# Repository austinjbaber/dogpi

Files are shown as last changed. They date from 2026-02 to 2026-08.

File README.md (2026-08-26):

# DogPi

**A self-contained Raspberry Pi appliance for logging dog bathroom activity, checking recent history, and viewing local weather from a tactile three-button interface.**

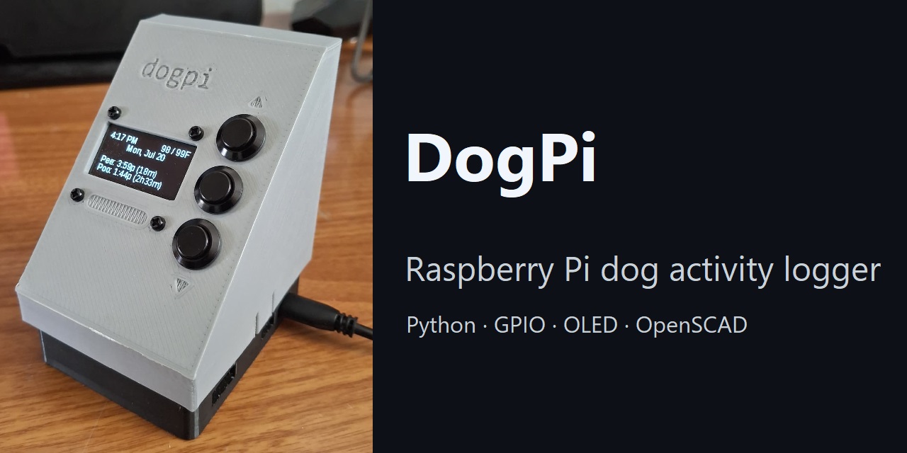
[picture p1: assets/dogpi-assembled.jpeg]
Assembled DogPi device


## Project overview

Coordinating pet care in a shared household can be surprisingly difficult. DogPi provides a simple, shared record of bathroom breaks on a purpose-built device that stays near the door. With a few button presses, anyone can log a pee, poop, or both, including an estimated time for an event recorded later. The OLED shows how long it has been and the current weather at a glance.

The project combines software, electronics, and mechanical design into one working product. It uses a state-driven embedded UI, GPIO input, durable local storage, a fault-tolerant weather integration, automated tests, and a custom 3D-printable enclosure.

## Key features

- Physical three-button interface with a six-state OLED UI
- Timestamped activity logging for pee, poop, or both, with an adjustable "how long ago" picker
- At-a-glance status showing the most recent events and current temperature
- Current weather stats and a scrollable hourly forecast from Open-Meteo
- Cached weather data with refresh throttling and stale-data fallback
- 5 configurable animated idle screens with real-time motion and bounded frame pacing
- Undo support and atomic JSON persistence across restarts
- Parametric OpenSCAD enclosure with ready-to-print STL files
- Automated regression tests for networking, caching, parsing, screen conversion, and timezones

## Architecture and engineering highlights

DogPi keeps hardware concerns, application state, screen rendering, and external services separated. `app.py` acts as the composition root: it loads configuration, creates the HTTP and weather services, injects the weather dependency into the UI, and then registers GPIO callbacks.

```text
Three GPIO buttons ──> input callbacks ──> UI state + screen rendering ──> SH1106 OLED
                                              │
                                              └──> atomic JSON event log

config.json ──> app.py
                  ├──> HttpService ──> WeatherService ──> Open-Meteo
                  │                     ├── implements IWeatherService
                  │                     └── injected clock
                  │
                  └──> screens.py <──── IWeatherService
```

Notable design decisions include:

- **Testable service boundaries:** screens depend on `IWeatherService`, while `WeatherService` depends on `IHttpService`. Tests can supply fakes without GPIO hardware or live network calls.
- **Resilient weather behavior:** refresh attempts are throttled, failed requests preserve the last successful result, and the UI identifies cached results as stale rather than discarding useful data.
- **Deterministic time handling:** the weather service accepts an injectable clock and interprets forecast values in the timezone returned by the API.
- **Safe local persistence:** events are first written to a temporary file and committed with `os.replace`, reducing the risk of a partially written log.
- **Hardware-aware animation:** idle renderers update motion using elapsed time rather than frame count. Rendering cadence is capped separately at 40 FPS to balance smoothness against CPU and I2C load.
- **Configuration outside the code:** coordinates, units, requested forecast fields, refresh timing, and forecast intervals live in `config.json`.

## Hardware and enclosure

| Component | Details |
|---|---|
| Computer | Raspberry Pi with GPIO and I2C. Enclosure designed for a Pi Zero 2 W |
| Display | 1.3-inch SH1106 OLED, 128 × 64, I2C (`0x3C`) |
| Controls | 3x momentary buttons: UP on GPIO 22, SELECT on GPIO 27, DOWN on GPIO 17 |
| Enclosure | Two-part parametric OpenSCAD design with committed base and lid STLs |

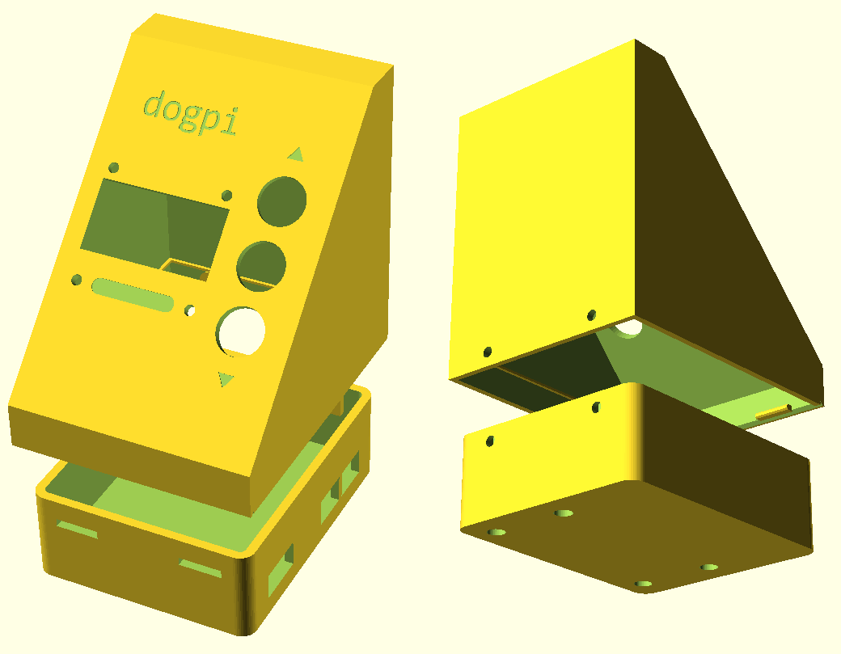
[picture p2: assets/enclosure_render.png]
Rendered DogPi enclosure


The enclosure integrates the Pi, display, and three vertically arranged 12 mm panel-mount buttons into an angled desktop control panel. Its OpenSCAD source exposes the following variables so tolerances can be adapted to a specific printer or filament:
- Fit
- Wall thickness
- Panel angle
- Port clearance
- Button spacing
- Front-tab and captive-nut closure clearances

See [`cad/README.md`](cad/README.md) for dimensions, printing instructions, and fit details.

## UI and controls

The interface is organized around six explicit modes:

- **Idle:** 5 dynamic, burn in-resistant animated backgrounds and DVD-style bouncing clock
- **Status:** Current date and time, most recent pee and poop times, and current local temp/feels-like temp
- **Menu:** Select from log pee/poo/both, undo, current weather, and forecast
- **When:** Selectable hours and 0/15/30/45-minute offset to log an event
- **Weather:** Scrollable current weather conditions
- **Forecast:** Scrollable hourly forecast (24-hour by default)

| Screen | UP | SELECT | DOWN |
|---|---|---|---|
| **Idle** | Cycle backgrounds | Open status | Cycle font |
| **Status** | — | Open menu | — |
| **Menu** | Previous | Select | Next |
| **When** | Increment | Next field / confirm | Decrement |
| **Weather** | Scroll up | — | Scroll down |
| **Forecast** | Scroll up | — | Scroll down |

Hold **SELECT** for 0.6 seconds to return to previous mode. After 25 seconds without input, the display returns to idle mode.

## Setup and usage

### 1. Enable I2C

```bash
sudo raspi-config
# Interface Options -> I2C -> Enable
sudo reboot
```

OLED can be checked after reboot with `i2cdetect -y 1`
The default display address is `0x3C`.

### 2. Install dependencies

```bash
sudo apt update
sudo apt install -y python3-pip i2c-tools fonts-dejavu fonts-liberation fonts-freefont-ttf
pip3 install -r requirements.txt
```

### 3. Configure weather

Weather uses Open-Meteo and does not require an API key.
Edit `config.json` to set:
- `request_parameters.latitude` and `request_parameters.longitude` for the forecast location
- `request_parameters` for units and requested current/daily/hourly fields
- `refresh_interval_seconds` for the minimum interval between attempts (default: 600)
- `forecast_horizon_hours` for the number of upcoming entries retained (default: 24)

The committed coordinates point to Tucson, Arizona.

### 4. Run DogPi

Run from the project directory so the event log is read and written there:

```bash
python3 app.py
```

Events are stored locally in `dog_log.json`:

```json
{
  "events": [
    {"type": "dog", "value": "pee", "ts": "2026-02-18T14:30:00"},
    {"type": "dog", "value": "both", "ts": "2026-02-18T08:15:00"}
  ]
}
```

## Tests

Run the complete suite from the project directory:

```bash
python3 -m pytest -q
```

The tests exercise time and direction helpers, HTTP transport failures, weather parsing and caching, refresh throttling, stale-data fallback, timezone interpretation, dependency reuse, and conversion of service models into OLED-ready views.

## Project structure

```text
dogpi/
├── app.py                     Root, main display loop
├── config.py                  Configuration
├── config.json                Weather location, fields, units, and timing
├── hardware.py                GPIO buttons, SH1106 setup, shared fonts
├── inputs.py                  Button callbacks, state transitions
├── screens.py                 UI state, view models, and OLED rendering
├── state.py                   Atomic event persistence and lookup helpers
├── helpers/                   Time, direction, and numeric helpers
├── idle/                      Idle renderer, animated backgrounds
├── services/
│   ├── http/                  HTTP interface, implementation, response model
│   └── weather/               Weather interface, adapter, cache, data models
├── cad/                       Parametric OpenSCAD source, printable STLs
├── assets/                    Assembled device photo, enclosure render
├── tests/                     Automated regression suite
└── requirements.txt           Python dependencies
```

### Idle animation tuning

Idle motion uses elapsed seconds (`dt`), with speed constants expressed in per-second units. Frame pacing is configured independently in `idle/__init__.py`:

```python
IDLE_TARGET_FPS = 40.0
```

For an SH1106 display over I2C, 24–40 FPS is a practical tuning range depending on the desired smoothness and available CPU/I2C capacity.

## Potential next steps

- Add a short animated demo and a full video walkthrough of the hardware, UI, and enclosure
- Expand the weather screen with a navigable multi-day forecast
- Reuse the HTTP service abstraction for additional features
- Implement test automation with GitHub Actions

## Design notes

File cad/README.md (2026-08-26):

# DogPi enclosure CAD

This directory contains the printable enclosure for DogPi. The enclosure is
designed around a **Raspberry Pi Zero 2 W**, a **1.3-inch SH1106 OLED**, and
three **12 mm momentary panel-mount buttons** arranged vertically on the angled
control deck. Dimensions in the OpenSCAD source are in millimetres.

## Files

| File | Description |
| --- | --- |
| `dogpi.scad` | Parametric OpenSCAD source for the base, lid, cutouts, and markings. |
| `base.stl` | Ready-to-slice base. Its mesh bounds are 60 × 75 × 25 mm. |
| `lid.stl` | Ready-to-slice lid. Its mesh bounds are approximately 64.2 × 112.0 × 64.5 mm. |

## Intended hardware

### Raspberry Pi

The model uses the Raspberry Pi Zero 2 W board outline and mounting pattern:

| Feature | Modelled value |
| --- | ---: |
| PCB outline | 65 × 30 mm |
| Mounting-hole spacing | 58 × 23 mm |
| Hole inset from PCB edges | 3.5 mm |
| Printed clearance-hole diameter | 2.8 mm |
| Exterior screw-head counterbore | 5 mm diameter × 3 mm deep |

The Pi is rotated 90 degrees inside the base so the mini-HDMI and two micro-USB
connectors face the right wall. The port cutouts are based on connector center
positions from the Pi drawing.

### OLED

The lid is intended for a 1.3-inch, 128 × 64 SH1106 I2C OLED module with this
mounting geometry:

| Feature | Modelled value |
| --- | ---: |
| Visible-window opening | 34 × 18 mm |
| Mounting-hole spacing | 30.4 × 28.5 mm |
| Printed mounting-hole diameter | 2.75 mm |

The window is intentionally smaller than the module PCB. Compare these values
with the drawing or a physical measurement of your module before printing;
boards sold as “1.3-inch SH1106” may not all use the same PCB or hole pattern.

### Buttons

The control deck accepts three nominal 12 mm panel-mount momentary buttons:

| Feature | Modelled value |
| --- | ---: |
| Printed panel-hole diameter | 12.2 mm |
| Vertical centre-to-centre spacing | 16 mm |
| Arrangement | UP / SELECT / DOWN |

Check the diameter of the threaded barrel rather than the button-cap diameter.

### Fasteners

The complete enclosure uses:

- 8 × M2.5 × 8 mm screws
- 2 × M2.5 × 6 mm screws
- 10 × M2.5 nuts
- 4 × M2.5 washers (1 mm thick)

Four screw-and-nut sets mount the Raspberry Pi and four mount the OLED. The
1 mm washers provide the intended spacing for the Pi board. The remaining two
nuts drop into the rear closure pockets. An 8 mm screw can be used for
the closure if that is what the standoff kit provides, but it may extend
into the wiring cavity.

### Lid closure and assembly

There are two rigid front tuck tabs and two rear captive-nut screws.

1. Insert one M2.5 nut into each open slot in the two rear base bosses.
2. Hold the rear of the lid slightly raised and insert both front tabs into the
   receiver slots.
3. Pivot the rear of the lid down. Do not force the lid as a fixed hinge.
   Continue until the three-sided internal stop lip rests on the base rim.
4. Insert an M2.5 screw through each rear lid hole and tighten it into the
   captive nut.

The closure screws use the same M2.5 hardware as the Pi mounts. Their
printed clearance holes are 3.0 mm rather than the Pi holes' 2.8 mm because the
rear screws pass horizontally through two printed walls and need reliable FDM
clearance. The rear holes are not counterbored.

Each default front tab is 11 mm wide, and each receiver is 11.5 mm wide for
0.25 mm clearance at either side. The two independent receivers tolerate minor
front-wall bowing better than one long, continuous mating feature.

## Important OpenSCAD parameters

Commonly adjusted values are near the top of `dogpi.scad`.

| Parameter | Default | Purpose |
| --- | ---: | --- |
| `$fn` | `48` | Curved-feature resolution. |
| `show_base`, `show_lid` | `true`, `true` | Select which parts are rendered or exported. |
| `show_assembled` | `false` | Switch between assembled and exploded preview. |
| `explode_gap` | `16` | Preview separation between the base and lid. |
| `render_target` | `0` | CLI/export selector described below. |
| `fit` | `0.30` | Lid clearance per side; the lid cavity grows by `2 * fit` in X and Y. |
| `button_hole_clear` | `0.20` | Extra diameter added to each nominal 12 mm button hole. |
| `oled_mount_hole_clear` | `0.25` | Extra diameter added to each nominal 2.5 mm OLED hole. |
| `wall` | `2.4` | Base wall thickness. |
| `floor_t` | `3.8` | Base floor thickness. |
| `face_t` | `3.0` | Lid/control-deck shell thickness. |
| `skirt_t`, `skirt_h` | `1.8`, `8` | Lid skirt wall thickness and overlap. |
| `panel_angle` | `45` | Control-deck angle in degrees. |
| `pi_mount_clear_d` | `2.8` | Pi mounting-hole diameter. |
| `side_port_clear` | `0.50` | Clearance added around the side connector openings. |
| `oled_window_x`, `oled_window_y` | `34`, `18` | OLED viewing-window dimensions. |
| `oled_hole_dx`, `oled_hole_dy` | `30.4`, `28.5` | OLED mounting-hole centre spacing. |
| `btn_col_x` | `19` | Horizontal location of the button column. |
| `btn_step_y` | `16` | Button center spacing along the sloped deck. |
| `font_i` | `9` | Selects the font used for the recessed `dogpi` marking. |

The closure can be tuned with `front_tab_w`, `front_tab_depth`, `front_tab_t`,
`front_tab_xy_clear`, `front_tab_z_clear`, `front_receiver_depth`,
`pivot_preview_slide`, `closure_screw_d`, `closure_nut_af`, `closure_nut_t`, and
`closure_nut_clear`. Receiver depth, tab depth, and slide travel are coupled:
keep each receiver deeper than the tab projection by at least the slide travel
plus the desired back clearance. Measure the nuts in the intended hardware kit
before changing their pocket dimensions.

## Rendering and exporting

Open `dogpi.scad` in OpenSCAD and use a full render (`F6`) before exporting.
For an interactive preview, leave `render_target = 0` and use the existing
`show_base`, `show_lid`, and `show_assembled` controls. For deterministic CLI
rendering and exports, set `render_target` to one of these values:

- `1`: base only, at its manufacturing origin
- `2`: lid only, at its manufacturing origin
- `3`: closed assembly
- `4`: closure section with representative M2.5 hardware
- `5`: closed-assembly interference diagnostic
- `6`: front-tab pivot-and-slide preview at the selected path angle
- `7`: interference diagnostic at the same selected path angle
- `8`: lid only, with control deck down for printing

Targets `5` and `7` should be empty; any visible solid represents an overlap.
Target `7` defaults to the middle of the assembly path (`3.75` degrees). For a
full path check, override `pivot_preview_angle` and repeat target `7` at intervals
from `0` through `pivot_path_max_angle` (`6.5` degrees). OpenSCAD's "current top
level object is empty" message is the passing result for these options.

The committed base and lid STLs are exported from targets `1` and `8`. Both have
a minimum Z coordinate of 0 and can be imported directly into a slicer.

## Known fit and tolerance limitations

- Clearances are tuned parametrically, not guaranteed for every printer,
  material, layer height, or shrink rate. Print a small fit test or be prepared
  to adjust `fit` in gradual steps.
- The closure is intended to print in PLA. The front tabs are rigid locating
  features rather than flexing snaps; tune tab and nut-pocket clearances for the
  specific printer and filament. PETG is also suitable when additional impact
  toughness is desired.
- The default captive-nut pockets assume a 4.8 mm across-flats, 2.0 mm thick
  M2.5 nut with 0.25 mm modelled clearance. Exact hardware dimensions can vary,
  measure before printing.
- The OLED opening and 30.4 × 28.5 mm hole pattern fit only matching modules.
  Connector position, PCB outline, and glass placement vary among SH1106 boards.
- The 12.2 mm button holes assume a nominal 12 mm mounting barrel. Panel buttons
  with keyed bodies or unusually thick retaining nuts may not fit.
- Side access is provided for mini-HDMI and two micro-USB connectors. Oversized
  cable shells may need more than the default 0.5 mm port clearance.
- There is no external microSD-card opening in the current model.
- The branding font depends on fonts installed on the computer rendering the
  SCAD file. If the selected font is unavailable, choose another `font_i` and
  verify the resulting text before export.
- The supplied STLs contain the current parameter values only. Changing the
  SCAD source does not update them, re-render and re-export if you make changes.

Dry-fit the Pi, OLED, buttons, and all cables before tightening the hardware.
Avoid overtightening against both printed plastic and the PCBs.

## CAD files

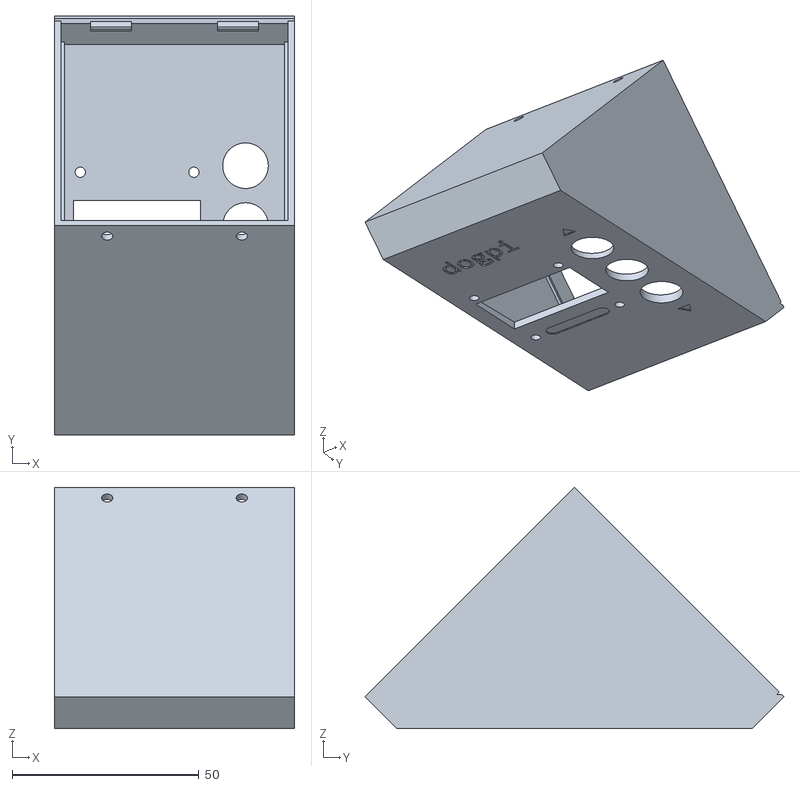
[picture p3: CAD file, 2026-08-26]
cad/lid.stl
64.2 x 112.0 x 64.5

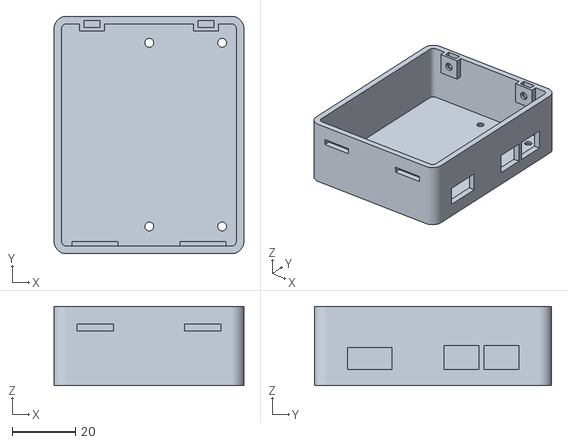
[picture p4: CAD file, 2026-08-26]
cad/base.stl
60.0 x 75.0 x 25.0

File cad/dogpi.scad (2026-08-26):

////\\/\\//\\//\\//\\//\\//\\//\\//\\//\\//\\//\\//\\//\\//\\//\\//\\//\\//\\//\\//
// Author: Austin Baber (github.com/austinjbaber)
// DogPi enclosure v8 - front tuck-tabs and rear screw closure
// Raspberry Pi Zero 2 W + 1.3" SH1106 OLED + 3x 12mm momentary buttons
//\\/\\//\\//\\//\\//\\//\\//\\//\\//\\//\\//\\//\\//\\//\\//\\//\\//\\//\\//\\//

$fn = 48;

// -----------------------------------------------------------------------------
// View controls
// -----------------------------------------------------------------------------
show_base = true;
show_lid = true;
show_assembled = false;   // false = exploded view
explode_gap = 16;

// -----------------------------------------------------------------------------
// Printer / fit tuning
// -----------------------------------------------------------------------------
fit = 0.30;                // general lid-to-base clearance
button_hole_clear = 0.20;  // extra diameter added to 12 mm button holes
oled_mount_hole_clear = 0.25; // extra diameter added to OLED M2.5 mounting holes

//\\/\\//\\//\\//\\//\\//\\//\\//\\//\\//\\//\\//\\//\\//\\//\\//\\//\\//\\//\\//
// General case params
//\\/\\//\\//\\//\\//\\//\\//\\//\\//\\//\\//\\//\\//\\//\\//\\//\\//\\//\\//\\//
wall = 2.4;      // base wall thickness
floor_t = 3.8;   // base floor thickness
face_t = 3.0;    // lid/control-deck shell thickness
skirt_t = 1.8;   // lid skirt wall thickness
skirt_h = 8;   // how far the lid overlaps down over the base
corner_r = 4.0;  // outside corner radius

base_x = 60;    // overall base width  (left/right)
base_y = 75;     // overall base depth  (front/back)
base_h = 25;   // overall base height

lid_inner_x = base_x + 2*fit;
lid_inner_y = base_y + 2*fit;
lid_x = lid_inner_x + 2*skirt_t;
lid_y = lid_inner_y + 2*skirt_t;

// -----------------------------------------------------------------------------
// Shared closure and assembly parameters
// -----------------------------------------------------------------------------
closure_screw_x = 18.0;        // left/right screw centers
closure_screw_d = 3.0;         // horizontal M2.5 clearance for FDM printing
closure_screw_z = base_h - skirt_h/2; // base/global Z = 21 mm
closure_screw_lid_z = closure_screw_z - (base_h - skirt_h);

pivot_path_max_angle = 6.5;
pivot_preview_angle = 3.75;     // middle of the validated assembly path
pivot_preview_slide = 0.27;    // peak temporary +Y travel while lowering rear
interference_test_gap = 0.01; // ignores the intentional stop-lip/rim contact

////\\/\\//\\//\\//\\//\\//\\//\\//\\//\\//\\//\\//\\//\\//\\//\\//\\//\\//\\//\\//
// Lid parameters
////\\/\\//\\//\\//\\//\\//\\//\\//\\//\\//\\//\\//\\//\\//\\//\\//\\//\\//\\//\\//

// -----------------------------------------------------------------------------
// Front tuck-tab closure
// -----------------------------------------------------------------------------
// Two rigid tongues on the low/front lid skirt enter matching receivers in the
// base. The rear then pivots down and is retained by two horizontal M2.5 screws
// threaded into drop-in captive nuts.
front_tab_x = 17.0;            // left/right tab centers
front_tab_w = 11.0;
front_tab_depth = 2.1;         // projection from the lid skirt into the base
front_tab_t = 1.6;
front_tab_lid_z = 1.4;         // low placement leaves room for the lid to pivot
front_tab_root_overlap = 0.40;
front_tab_nose_bevel = 0.45;

front_skirt_bevel = 1.00;      // lower-inner clearance during pivot-and-slide
closure_bearing_pad_d = 7.0;
closure_bearing_pad_depth = 0.20;

// -----------------------------------------------------------------------------
// Angled control deck geometry
// -----------------------------------------------------------------------------
panel_angle = 45;               // display/button plane angle
rear_deck_d = 12;             // flat rear band after slope ends
roof_low_top_z = skirt_h + 4.0; // top height at front edge of lid

// Slope starts immediately at the front edge
panel_rear_y = lid_y/2 - rear_deck_d;
panel_run_y = panel_rear_y + lid_y/2;

roof_high_top_z = roof_low_top_z + tan(panel_angle) * panel_run_y;

// Midpoint of the sloped section, used by panel_frame()
panel_mid_y = (-lid_y/2 + panel_rear_y) / 2;
panel_mid_z = (roof_low_top_z + roof_high_top_z) / 2;

// -----------------------------------------------------------------------------
// OLED module
// -----------------------------------------------------------------------------
oled_hole_d = 2.5 + oled_mount_hole_clear;
oled_hole_dx = 30.4;
oled_hole_dy = 28.5;

// Target physical window opening in lid
oled_window_x = 34.0;
oled_window_y = 18.0;

oled_window_center_y = 11.25 - oled_window_y/2;  // = 2.25
oled_window_offset_x = 0.0;

// OLED centered on the angled deck
// In local panel coordinates: x is left/right across case, y is up/down along the deck.
oled_lx = -10;
oled_ly = 0;

// -----------------------------------------------------------------------------
// 12 mm panel buttons
// -----------------------------------------------------------------------------
button_panel_hole = 12.0 + button_hole_clear;

// single vertical button column to the right of the OLED
btn_col_x  = 19;
btn_step_y = 16.0;   // center-to-center spacing from middle to top/bottom

btn_up_y   =  btn_step_y;
btn_sel_y  =  0;
btn_down_y = -btn_step_y;

// shared list so placement only lives in one place
button_positions = [
    [btn_col_x, btn_up_y],
    [btn_col_x, btn_sel_y],
    [btn_col_x, btn_down_y]
];

// -----------------------------------------------------------------------------
// Lid branding / button markers / pill recess
// -----------------------------------------------------------------------------

// font sampler: change this index and re-render
// if one doesn't exist on your system, try another
font_options = [
    "Arial:style=Bold",
    "Verdana:style=Bold",
    "Trebuchet MS:style=Bold",
    "Segoe UI:style=Bold",
    "Bahnschrift:style=Bold",
    "Liberation Sans:style=Bold",
    "DejaVu Sans:style=Bold",
    "Helvetica:style=Bold",
    "Lucida Console:style=Bold",
    "Consolas:style=Regular",
    "Consolas:style=Bold"
];
font_i = 9;
brand_font = font_options[min(max(font_i, 0), len(font_options)-1)];

brand_text = "dogpi";
brand_size = 7;
brand_spacing = 1.0;
brand_depth = 0.40;

// local panel coordinates
// x = left/right across lid
// y = along the sloped deck
brand_x = -10;
brand_y = btn_up_y + 15.0;   // above select button

tri_enable = true;
tri_depth = 0.35;
tri_w = 4.2;
tri_h = 3.3;
tri_x = btn_col_x;   // aligned with button column

under_oled_recess_enable = true;
under_oled_recess_depth  = 0.35;
under_oled_recess_x      = oled_lx;
under_oled_recess_y      = oled_ly - oled_hole_dy/2;
under_oled_recess_w      = 22.0;
under_oled_recess_h      = 4.0;
under_oled_recess_r      = 2;

// -----------------------------------------------------------------------------
// Inner stop lip (3-sided)
// -----------------------------------------------------------------------------
stop_lip_inset  = 0.9;   // how far the lip projects inward
stop_lip_h      = 0.7;   // lip thickness upward from z = skirt_h
stop_lip_shell_overlap = 0.15;

////\\/\\//\\//\\//\\//\\//\\//\\//\\//\\//\\//\\//\\//\\//\\//\\//\\//\\//\\//\\//
// Base parameters
////\\/\\//\\//\\//\\//\\//\\//\\//\\//\\//\\//\\//\\//\\//\\//\\//\\//\\//\\//\\//

// -----------------------------------------------------------------------------
// Raspberry Pi Zero 2 W
// -----------------------------------------------------------------------------
pi_x = 65.0;
pi_y = 30.0;
pi_hole_inset = 3.5;
pi_hole_dx = 58.0;
pi_hole_dy = 23.0;

pi_mount_clear_d = 2.8;

pi_counterbore_d = 5.0;   // counterbore diameter
pi_counterbore_h = 3.0;   // counterbore depth

pi_right_gap = 1;
pi_rear_gap = 2.5;
// Pi is rotated 90 degrees so ports face the right wall.
pi_origin_x =  base_x/2 - wall - pi_right_gap - pi_y;
pi_origin_y =  base_y/2 - wall - pi_rear_gap - pi_x;

// -----------------------------------------------------------------------------
// Port tunnel params (based on Pi drawing X positions)
// -----------------------------------------------------------------------------
side_tunnel_x = base_x/2 - wall - 0.6;
side_tunnel_depth = wall + 1.2;
side_port_clear = 0.50;
side_port_z = 5.1;

// Connector opening sizes before applying side_port_clear in Y.
mini_hdmi_w = 13.0;
mini_hdmi_h = 7.0;
micro_usb_w = 10.0;
micro_usb_h = 7.5;

// Board-view connector center X positions (from the Pi drawing/blueprint)
mini_hdmi_c = 12.4;
usb1_c      = 41.4;
usb2_c      = 54.0;
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

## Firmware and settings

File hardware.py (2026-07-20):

"""Hardware setup — buttons, OLED display, and fonts."""

from gpiozero import Button
from luma.core.interface.serial import i2c
from luma.oled.device import sh1106
from PIL import ImageFont

I2C_ADDR = 0x3C

# ----------------------------
# Buttons
# ----------------------------
BTN_DOWN   = Button(17, pull_up=True, bounce_time=0.12)
BTN_SEL  = Button(27, pull_up=True, bounce_time=0.12)
BTN_UP = Button(22, pull_up=True, bounce_time=0.12)

# ----------------------------
# OLED
# ----------------------------
serial = i2c(port=1, address=I2C_ADDR)
device = sh1106(serial)
W, H = device.size

# ----------------------------
# Fonts
# ----------------------------
def try_font(path, size):
    try:
        return ImageFont.truetype(path, size)
    except Exception:
        return None

SCREEN_FONT = (
    try_font("/usr/share/fonts/truetype/liberation/LiberationSans-Regular.ttf", 12)
    or ImageFont.load_default()
)

TOAST_FONT = (
    try_font("/usr/share/fonts/truetype/freeFont/FreeMono.ttf", 12)
    or SCREEN_FONT
)

WHEN_FONT = (
    try_font("/usr/share/fonts/truetype/dejavu/DejaVuSans-Bold.ttf", 12)
    or SCREEN_FONT
)

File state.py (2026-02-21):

"""Persistence — JSON log and event helpers."""

import json
import os

DATA_PATH = "dog_log.json"


def load_state():
    if not os.path.exists(DATA_PATH):
        return {"events": []}
    with open(DATA_PATH, "r") as f:
        return json.load(f)


def save_state(st):
    tmp = DATA_PATH + ".tmp"
    with open(tmp, "w") as f:
        json.dump(st, f)
    os.replace(tmp, DATA_PATH)


state = load_state()


def log_event(ev):
    state["events"].append(ev)
    save_state(state)


def last_dog_where(pred):
    for ev in reversed(state["events"]):
        if ev.get("type") == "dog" and pred(ev):
            return ev
    return None

def undo_last_dog_event():
    """Remove and return the most recent event with type == 'dog'.

    Returns the removed event dict, or None if there was no dog event to remove.
    """
    # iterate backwards to find the most recent dog event
    for i in range(len(state["events"]) - 1, -1, -1):
        ev = state["events"][i]
        if ev.get("type") == "dog":
            removed = state["events"].pop(i)
            save_state(state)
            return removed
    return None

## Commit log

2026-02-27 Refactor/centralize helper functionality (#3)
    * refactors helper code so it's all in one place and adds readability enhancements
    * Adds 12 hour time and long date helper functions, and more readability enhancements
    * Changes module docstring to be generic, opposed to time specific
    * Splits helpers into their own respective files, and adds tests to ensure existing functionality isn't broken.
    * Fixes a potential bug were get_12_hour_clock_time() is not being passed the expected value.
    * The from helpers import * in screens.py was pulling in time (the datetime.time class) from time_helpers.py. Added __all__ to time_helpers.py so the importing only exports the helper functions, not the re-i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
    [screens.py]
2026-03-11 Feature/idle screen revamp (#6)
    * added font cycling (with down button) to idle screen
    * added icosahedron for idle background cycling
    * Refactor/idle screen (#5)
    * added another background (starfield) and modularized idle.py into a package
    * synchronized starfield vanishing point with clock bounce, slowed max_spd
    * slowed clock bounces even more
    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
2026-07-21 added image assets and .scad/.stl files
    [dogpi.scad, dogpi_base.stl, dogpi_lid.stl]
2026-08-12 Enclosure/hdmi port (#10)
    * adjusted ports to compensate connectors
    * updated .stl files
    [dogpi.scad, dogpi_base.stl]
2026-08-26 Redesign lid retention (#11)
    * Add independent front tuck-tab closure
    * new print orientation for lid, updated .stl exports
    * updated cad/README.md
    * fixed filename typo
    [base.stl, dogpi.scad, dogpi_base.stl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]
